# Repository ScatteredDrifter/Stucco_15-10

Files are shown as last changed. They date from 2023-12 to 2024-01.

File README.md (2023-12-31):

# STUCCO \[10-15\]
orthogonal **TKL** that comes in either **5** or **4** row design. 

## current status:
An internal GB was started and fulfilled by **Technofrikus**. 
They also designed a case for this pcb which they offer to print. 

**Besides there are some issues:**

- stabilizier orientation wrong for bottom row ( row5 )
- breaking of the lower row disables the two middle switches in row4 ( because I made a mistake for connecting the diodes accordingly)
- **this should be fixed afaik**

## Features: 

- built upon **rp2040**
- VIAL and QMK support ( technically ZMK possible too, yet not planned)
- GPIO-pinouts for additional features 

## Layout:

Possible layouts available for this pcb are pictured below. 

>**Beware** one can only reduce the amount of rows once ( as you permantly break off the lower row!).

picture denoting all possible switch layouts possible with the pcb 

## Images: 

Below you may find some images taken from the pcb and some built keyboards:

### PCB:

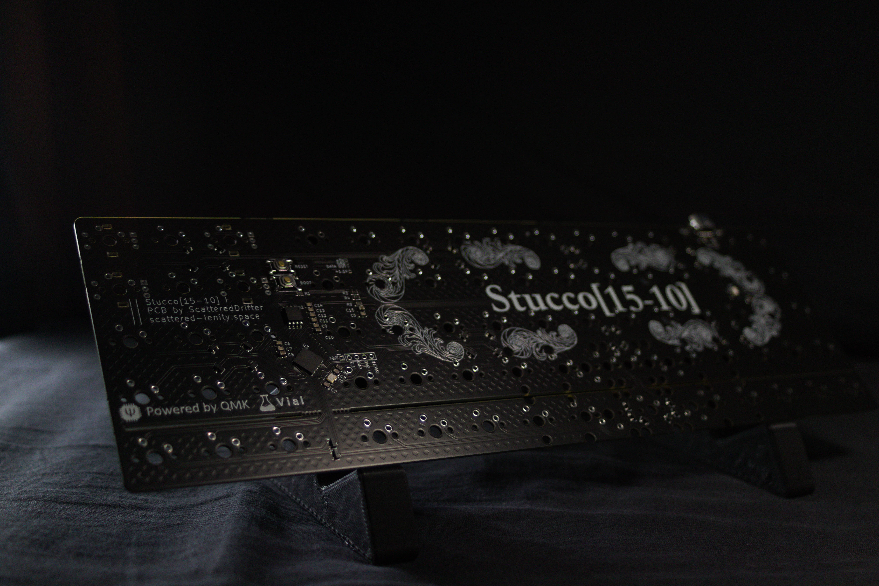
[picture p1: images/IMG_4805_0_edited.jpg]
back-image of pcb


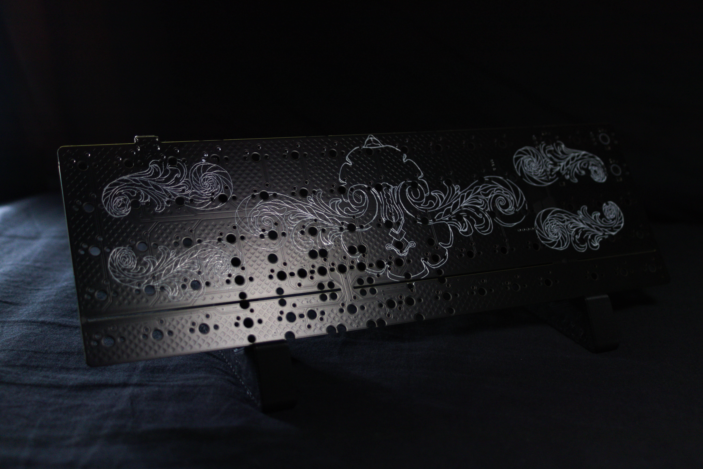
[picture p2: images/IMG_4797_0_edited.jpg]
front-image of pcb


### built Keyboard:

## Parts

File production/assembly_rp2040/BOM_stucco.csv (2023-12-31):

Comment | Designator | Footprint | LCSC
10u | C1,C4,C15 | Capacitor_SMD:C_0805_2012Metric | C91245
22pf | C2,C3 | Capacitor_SMD:C_0805_2012Metric | C1804
100n | C5,C6,C7,C9,C11,C12,C13,C14 | Capacitor_SMD:C_0805_2012Metric | C49678
1u | C8,C10 | Capacitor_SMD:C_0805_2012Metric | C28323
BAV70 | D1,D2,D3,D4,D5,D6,D7,D8,D9,D10,D11,D12,D13,D14,D15,D16,D17,D18,D19,D20,D21,D22,D23,D24,D25,D26,D27,D28,D29,D30,D31,D32,D33,D34,D35,D36,D37,D38,D39,D40 | Package_TO_SOT_SMD:SOT-23 | C68978
polyfuse | F0 | Fuse:Fuse_1206_3216Metric | C69688
USB_C_Receptacle_USB2.0 | J0 | Connector_USB:USB_C_Receptacle_HRO_TYPE-C-31-M-12 | C165948
BREAKOUT | J1 | Connector_PinSocket_2.54mm:PinSocket_1x05_P2.54mm_Vertical
Conn_01x03_Male | J2 | Connector_PinSocket_1.27mm:PinSocket_1x03_P1.27mm_Vertical
Conn_01x01_Male | J4 | Connector_PinSocket_1.27mm:PinSocket_1x01_P1.27mm_Vertical
1k | R1,R5 | Resistor_SMD:R_0805_2012Metric | C115316
27 | R3,R4 | Resistor_SMD:R_0805_2012Metric | C104170
5.1k | R6,R7 | Resistor_SMD:R_0805_2012Metric | C27834
10k | R8 | Resistor_SMD:R_0805_2012Metric | C115309
RESET | SW-1 | Button_Switch_SMD:SW_Push_1P1T_NO_6x6mm_H9.5mm | C318884
BOOT | SW0 | Button_Switch_SMD:SW_Push_1P1T_NO_6x6mm_H9.5mm | C318884
SW_PUSH | SW1,SW2,SW_2,SW3,SW_3,SW4,SW_4,SW5,SW_5,SW6,SW_6,SW7,SW_7,SW8,SW_8,SW9,SW_9,SW10,SW_10,SW11,SW_11,SW12,SW_12,SW_13,SW14,SW_14,SW15,SW_15,SW16,SW17,SW18,SW19,SW20,SW21,SW22,SW23,SW24,SW25,SW26,SW27,SW28,SW29,SW30,SW31,SW32,SW33,SW34,SW35,SW36,SW37,SW38,SW39,SW40,SW41,SW42,SW43,SW44,SW45,SW46,SW47,SW48,SW49,SW50,SW51,SW52,SW53,SW54,SW55,SW56,SW57,SW58,SW59,SW60,SW61,SW25_1,SW29_1,SW29_2,SW29_3 | marbastlib-mx:SW_MX_1u
001 | SW_1 | marbastlib-mx:SW_MX_1u
RotaryEncoder_Switch | SWrot_1,SWrot_2,SWrot_1_1,SWrot_2_2 | cipulot_parts:RotaryEncoder_EC11
NCP1117-3.3_SOT223 | U1 | Package_TO_SOT_SMD:SOT-223-3_TabPin2 | C26537
W25Q128JVS | U2 | Package_SO:SOIC-8_5.23x5.23mm_P1.27mm | C97521
RP2040 | U3 | Footprints:RP2040-QFN-56 | C2040
SRV05-4 | U44 | Package_TO_SOT_SMD:SOT-23-6 | C85364
12MHZ Crystal | Y0 | Crystal:Crystal_SMD_3225-4Pin_3.2x2.5mm | C9002

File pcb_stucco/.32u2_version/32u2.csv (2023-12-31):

Comment | Designator | Footprint | LCSC
22pf | C0,C1 | Capacitor_SMD:C_0805_2012Metric | C1804
1uf | C2 | Capacitor_SMD:C_0805_2012Metric | C28323
.1uf / 100nf | C3,C4 | Capacitor_SMD:C_0805_2012Metric | C49678
10uf | C5 | Resistor_SMD:R_0805_2012Metric | C91245
BAV70 | D1,D2,D3,D4,D5,D6,D7,D8,D9,D10,D11,D12,D13,D14,D15,D16,D17,D18,D19,D20,D21,D22,D23,D24,D25,D26,D27,D28,D29,D30,D31,D32,D33,D34,D35,D36,D37,D38,D39,D40 | Package_TO_SOT_SMD:SOT-23
Polyfuse | F0 | Resistor_SMD:R_0805_2012Metric | C69688
USB_C_Receptacle_USB2.0 | J0 | Connector_USB:USB_C_Receptacle_HRO_TYPE-C-31-M-12 | C165948
10k | R0,R5 | Resistor_SMD:R_0805_2012Metric | C17414
22 | R1,R2 | Resistor_SMD:R_0805_2012Metric | C17561
5.1k | R3,R4 | Resistor_SMD:R_0805_2012Metric | C27834
SW_PUSH | SW0 | Button_Switch_SMD:SW_SPST_TL3342 | C318884
SW_PUSH | SW_2,SW_3,SW4,SW_5,SW_6,SW_7,SW_8,SW_9,SW_10,SW11,SW_11,SW12,SW_12,SW0_13,SW13,SW14,SW_14,SW15,SW_15,SW16,SW17,SW18,SW19,SW110,SW111,SW112,SW113,SW114,SW115,SW201,SW202,SW203,SW204,SW205,SW206,SW207,SW208,SW209,SW210,SW211,SW212,SW213,SW214,SW215,SW301,SW302,SW303,SW304,SW305,SW306,SW307,SW308,SW309,SW310,SW311,SW312,SW313,SW314,SW315,SW401,SW402,SW403,SW404,SW405,SW406,SW407,SW408,SW409,SW410,SW411,SW412,SW413,SW414,SW415,SW406_1,SW407_1,SW407_2,SW407_3 | kbd:keyswitch_cherrymx_alps_combo
001 | SW_1 | kbd:keyswitch_cherrymx_alps_combo
ATmega32U2-A | U0 | Package_QFP:TQFP-32_7x7mm_P0.8mm | C618733
SRV05-4 | U1 | Package_TO_SOT_SMD:SOT-23-6 | C85364
Crystal_GND24_Small | Y0 | Crystal:Crystal_SMD_3225-4Pin_3.2x2.5mm | C13738

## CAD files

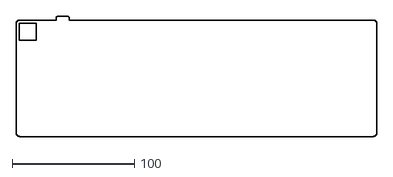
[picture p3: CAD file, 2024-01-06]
images/pcb_outlines_wout switches.dxf
295.3 x 98.2

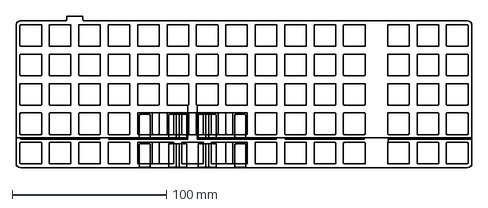
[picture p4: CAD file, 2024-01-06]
images/pcb_outlines.dxf
295.3 x 98.2 mm

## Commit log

2023-12-31 add pcb_files for stucco50
    [32u2.csv, 32u2.kicad_sch, kb_matrix.kicad_sch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]
2023-12-31 add readme, images of pcb
2024-01-01 fix issue with pcb
2024-01-06 ready filesfor v², fix routing
    [32u2.csv, 32u2.kicad_sch, BOM_stucco.csv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]
